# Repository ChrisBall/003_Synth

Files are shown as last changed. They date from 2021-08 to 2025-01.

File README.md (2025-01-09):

# 003_Synth
Code &amp; files for making my audio-lib based synth; 003

Based on a teensy 4.0 with assoc. audio board.

The synth is actually 2 devices - a teensy 4.0 with audio board and a separate "nano every"-based midi controller, with 48 pots, a rotary encoder and OLED display. 

Description of the contents of the code folder:

-"003_synth_main" contains the main arduino sketch.

-"Processing_003_controller_board" contains a basic processing sketch for controlling the synth using [the midibus](https://github.com/sparks/themidibus) library.

-"ctrlr interface" contains a similar midi interface for the [ctrlr software](https://github.com/RomanKubiak/ctrlr).

-"modified audio lib files" contains a modified delay effect for tape simulation. You'll need to replace the originals in the teensy audio lib folder.

-"nano_controller" contains the code that runs on the HMI controller.

You can use this code without building a controller - the synth can be controlled via MIDI. There is a processing program or ctrlr interface in the code folder to facilitate this.

Compilation notes:

-To compile my digital "tape" delay module you'll need to replace the teensy audio lib files (effect_delay.cpp and effect_delay.h) with my versions in the "modified audio lib files" folder.
-Build with "smallest code" option

To get it making a sound, there's some extra work:

-You'll need to set the master volume (CC44, channel 3 - the device only responds to controller values on channel 3). 
-To get sound through the effects chain, set the two distortion gains (CC25, CC41 - channel 3) which default to 0.
-To save a preset (SD card required) send program change on channel 16. To load: program change on channel 3. Presets are saved as plain text in folder "/PRESETS/" on the SD.

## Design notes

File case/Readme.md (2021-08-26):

These are the files for the laser cut case - but I encourage you to design your own controller.

The case is cut from 2mm ply, uses neutrik jack sockets for audio connections, and motherboard standoffs to mount the teensy and a MIDI breakout board.

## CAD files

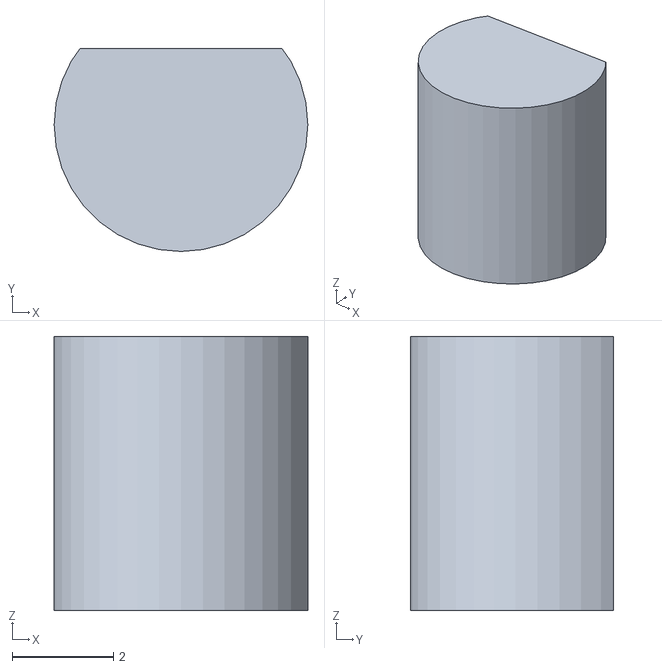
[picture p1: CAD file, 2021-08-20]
case/knobFiller.stl
5.00 x 4.00 x 5.40

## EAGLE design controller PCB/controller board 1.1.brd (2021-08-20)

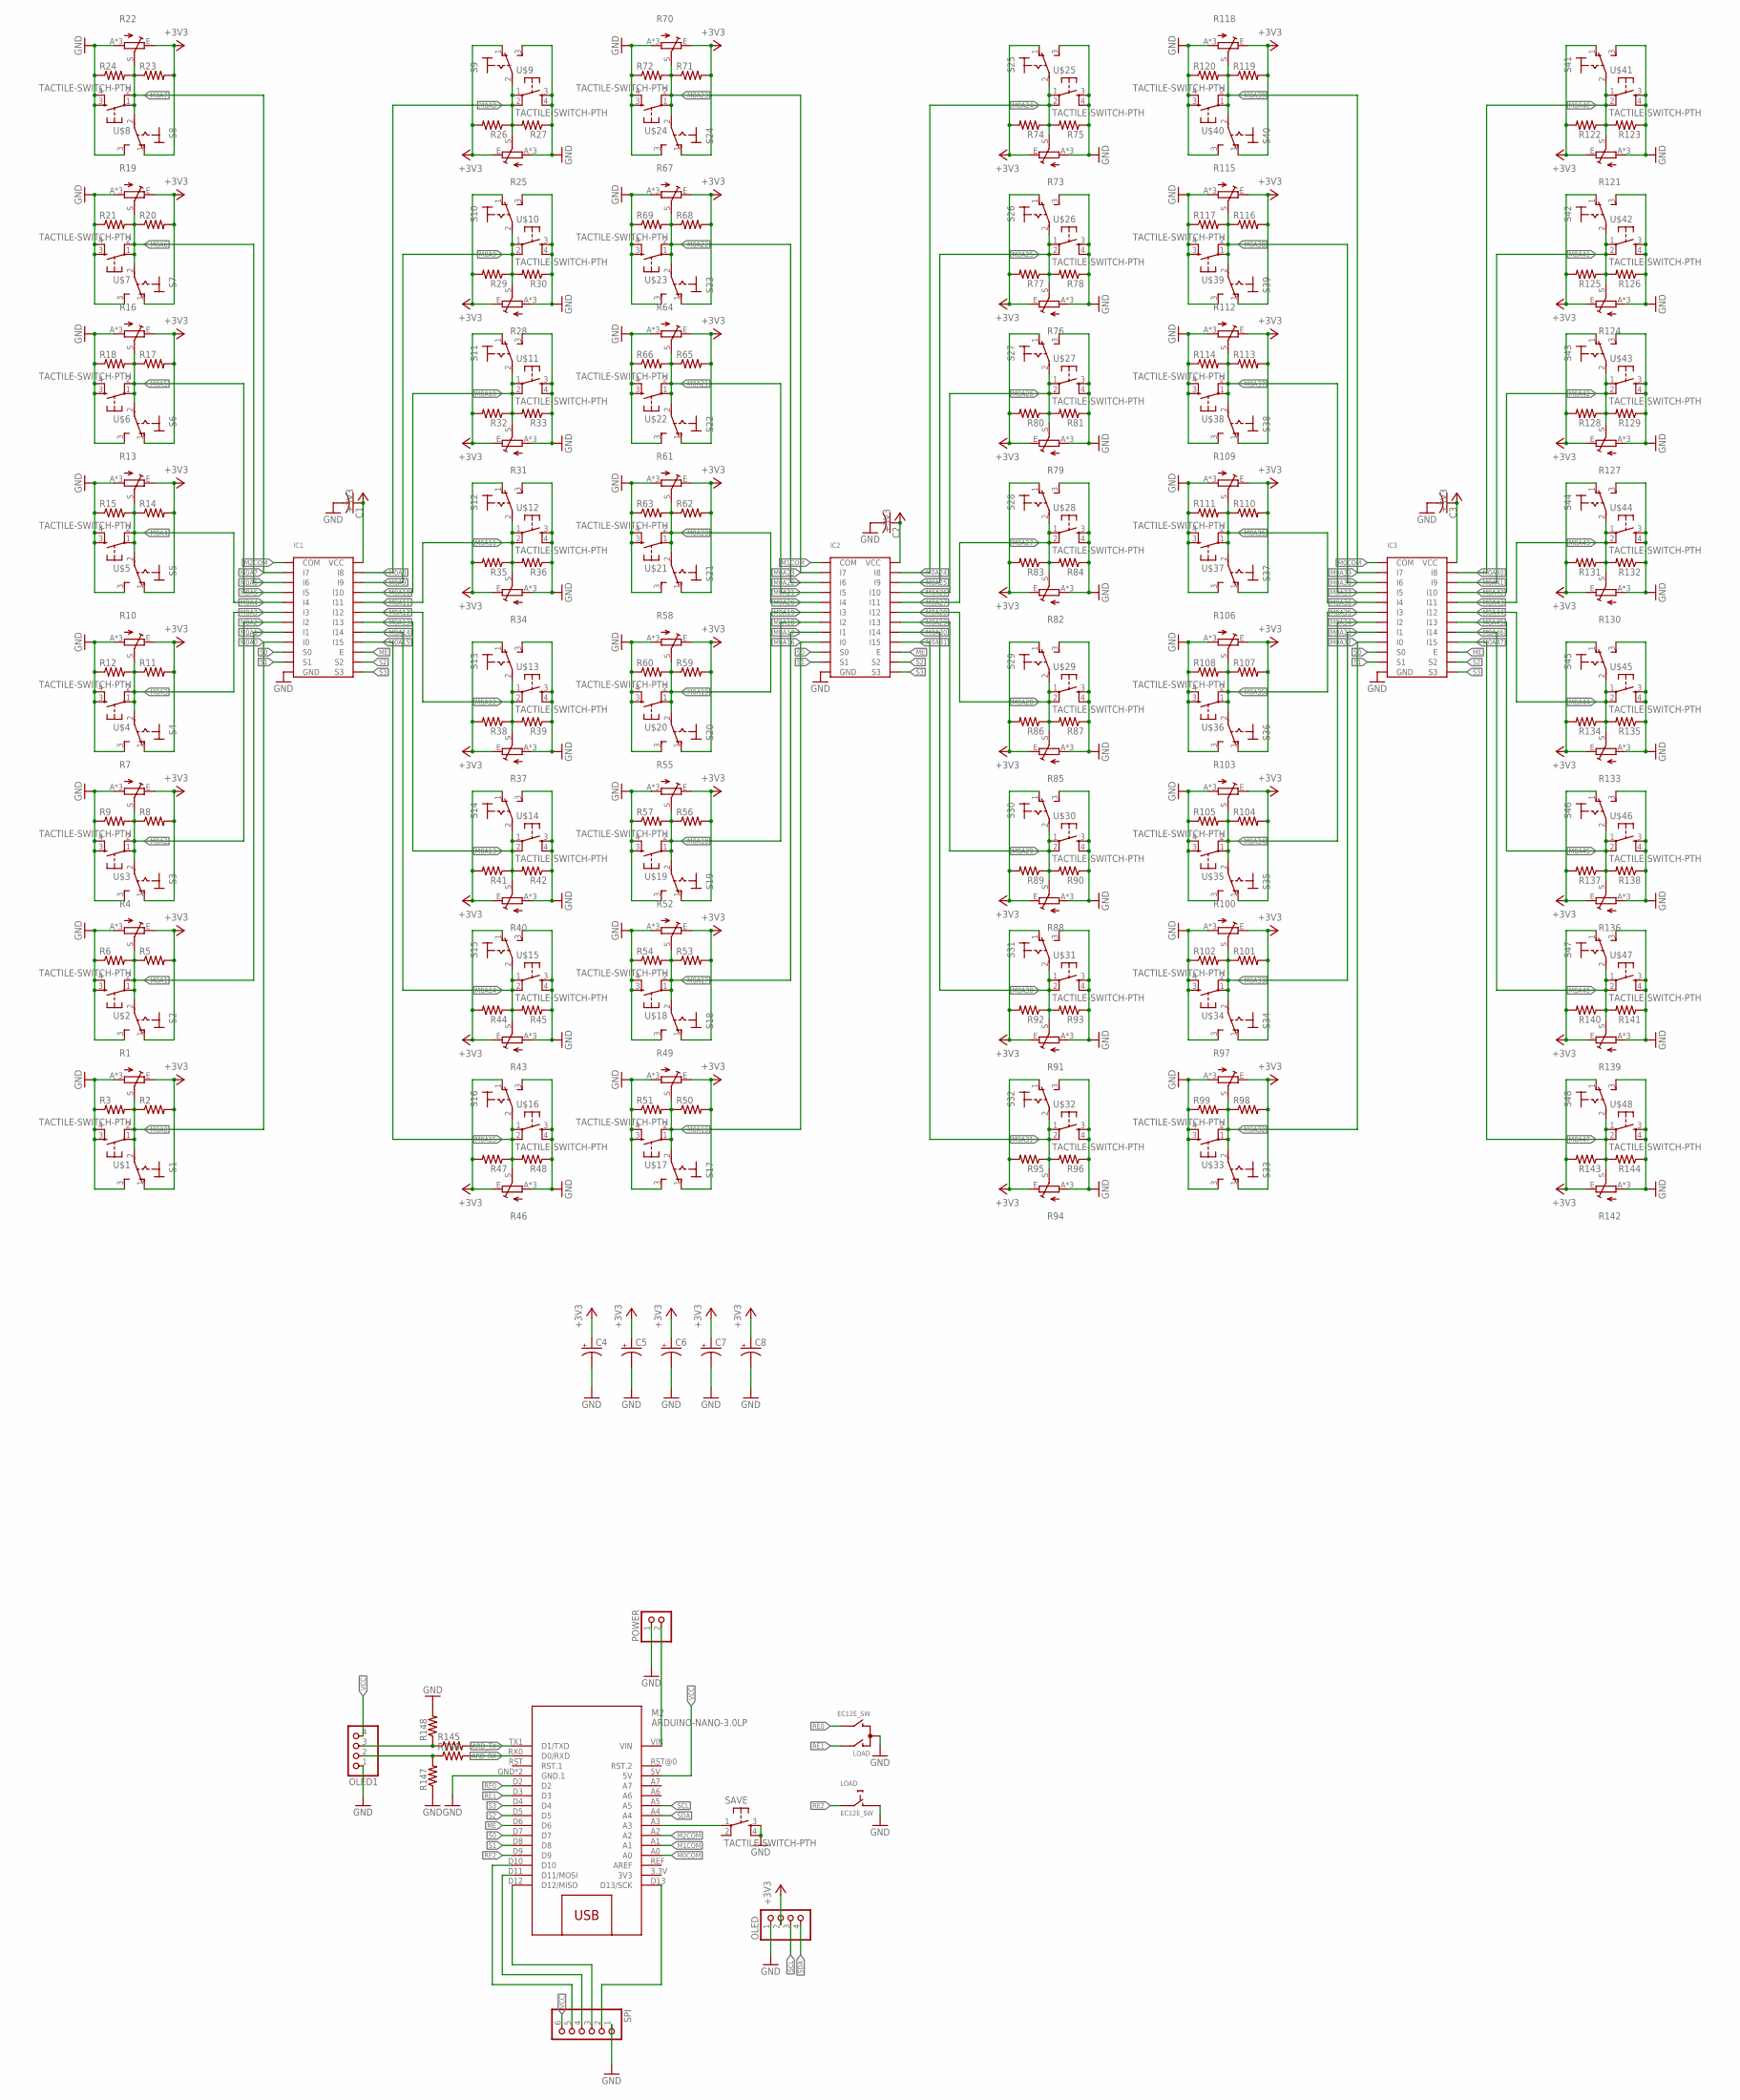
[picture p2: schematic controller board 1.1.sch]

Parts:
C1, C2, C3: C-USC0805; C0805
C4, C5, C6, C7, C8: CPOL-USE2.5-6; E2,5-6
IC1, IC2, IC3: CD74HC4067SM96; LP24SSOP
LOAD: EC12E_SW; ALPS_EC12E_SW
M2: ARDUINO-NANO-3.0LP; ARDUINO-NANO-3.0_LONGPADS
OLED, OLED1: PINHD-1X4; 1X04
POWER: PINHD-1X2; 1X02
R1, R4, R7, R10, R13, R16, R19, R22, R25, R28, R31, R34, R37, R40, R43, R46, R49, R52, R55, R58, R61, R64, R67, R70, R73, R76, R79, R82, R85, R88, R91, R94, R97, R100, R103, R106, R109, R112, R115, R118, R121, R124, R127, R130, R133, R136, R139, R142: TDS3_TRIM_EU-RK09LS; TDS3_RK09L
R2, R3, R5, R6, R8, R9, R11, R12, R14, R15, R17, R18, R20, R21, R23, R24, R26, R27, R29, R30, R32, R33, R35, R36, R38, R39, R41, R42, R44, R45, R47, R48, R50, R51, R53, R54, R56, R57, R59, R60, R62, R63, R65, R66, R68, R69, R71, R72, R74, R75, R77, R78, R80, R81, R83, R84, R86, R87, R89, R90, R92, R93, R95, R96, R98, R99, R101, R102, R104, R105, R107, R108, R110, R111, R113, R114, R116, R117, R119, R120, R122, R123, R125, R126, R128, R129, R131, R132, R134, R135, R137, R138, R140, R141, R143, R144, R145, R146, R147, R148: R-US_M0805; M0805
S1, S2, S3, S4, S5, S6, S7, S8, S9, S10, S11, S12, S13, S14, S15, S16, S17, S18, S19, S20, S21, S22, S23, S24, S25, S26, S27, S28, S29, S30, S31, S32, S33, S34, S35, S36, S37, S38, S39, S40, S41, S42, S43, S44, S45, S46, S47, S48: M9040P
SAVE: TACTILE-SWITCH-PTH; TAC-SWITCH-PTH
SPI: PINHD-1X6; 1X06
U$1, U$2, U$3, U$4, U$5, U$6, U$7, U$8, U$9, U$10, U$11, U$12, U$13, U$14, U$15, U$16, U$17, U$18, U$19, U$20, U$21, U$22, U$23, U$24, U$25, U$26, U$27, U$28, U$29, U$30, U$31, U$32, U$33, U$34, U$35, U$36, U$37, U$38, U$39, U$40, U$41, U$42, U$43, U$44, U$45, U$46, U$47, U$48: TACTILE-SWITCH-PTH; TAC-SWITCH-PTH

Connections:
3V3: M2.3.3V (3V3)
ARD_RX: M2.RX0 (D0/RXD), R146.2
ARD_TX: M2.TX1 (D1/TXD), R145.2
GND: C1.2, C2.2, C3.2, C4.-, C5.-, C6.-, C7.-, C8.-, IC1.GND, IC2.GND, IC3.GND, LOAD.C, LOAD.D (1), M2.GND (GND.1), M2.GND@1 (GND.1), OLED.1, OLED1.1, POWER.1, R1.A, R1.SNAPL (A), R1.SNAPR (A), R3.1, R4.A, R4.SNAPL (A), R4.SNAPR (A), R6.1, R7.A, R7.SNAPL (A), R7.SNAPR (A), R9.1, R10.A, R10.SNAPL (A), R10.SNAPR (A), R12.1, R13.A, R13.SNAPL (A), R13.SNAPR (A), R15.1, R16.A, R16.SNAPL (A), R16.SNAPR (A), R18.1, R19.A, R19.SNAPL (A), R19.SNAPR (A), R21.1, R22.A, R22.SNAPL (A), R22.SNAPR (A), R24.1, R25.A, R25.SNAPL (A), R25.SNAPR (A), R27.1, R28.A, R28.SNAPL (A), R28.SNAPR (A), R30.1, R31.A, R31.SNAPL (A), R31.SNAPR (A), R33.1, R34.A, R34.SNAPL (A), R34.SNAPR (A), R36.1, R37.A, R37.SNAPL (A), R37.SNAPR (A), R39.1, R40.A, R40.SNAPL (A), R40.SNAPR (A), R42.1, R43.A, R43.SNAPL (A), R43.SNAPR (A), R45.1, R46.A, R46.SNAPL (A), R46.SNAPR (A), R48.1, R49.A, R49.SNAPL (A), R49.SNAPR (A), R51.1, R52.A, R52.SNAPL (A), R52.SNAPR (A), R54.1, R55.A, R55.SNAPL (A), R55.SNAPR (A), R57.1, R58.A, R58.SNAPL (A), R58.SNAPR (A), R60.1, R61.A, R61.SNAPL (A), R61.SNAPR (A), R63.1, R64.A, R64.SNAPL (A), R64.SNAPR (A), R66.1, R67.A, R67.SNAPL (A), R67.SNAPR (A), R69.1, R70.A, R70.SNAPL (A), R70.SNAPR (A), R72.1, R73.A, R73.SNAPL (A), R73.SNAPR (A), R75.1, R76.A, R76.SNAPL (A), R76.SNAPR (A), R78.1, R79.A, R79.SNAPL (A), R79.SNAPR (A), R81.1, R82.A, R82.SNAPL (A), R82.SNAPR (A), R84.1, R85.A, R85.SNAPL (A), R85.SNAPR (A), R87.1, R88.A, R88.SNAPL (A), R88.SNAPR (A), R90.1, R91.A, R91.SNAPL (A), R91.SNAPR (A), R93.1, R94.A, R94.SNAPL (A), R94.SNAPR (A), R96.1, R97.A, R97.SNAPL (A), R97.SNAPR (A), R99.1, R100.A, R100.SNAPL (A), R100.SNAPR (A), R102.1, R103.A, R103.SNAPL (A), R103.SNAPR (A), R105.1, R106.A, R106.SNAPL (A), R106.SNAPR (A), R108.1, R109.A, R109.SNAPL (A), R109.SNAPR (A), R111.1, R112.A, R112.SNAPL (A), R112.SNAPR (A), R114.1, R115.A, R115.SNAPL (A), R115.SNAPR (A), R117.1, R118.A, R118.SNAPL (A), R118.SNAPR (A), R120.1, R121.A, R121.SNAPL (A), R121.SNAPR (A), R123.1, R124.A, R124.SNAPL (A), R124.SNAPR (A), R126.1, R127.A, R127.SNAPL (A), R127.SNAPR (A), R129.1, R130.A, R130.SNAPL (A), R130.SNAPR (A), R132.1, R133.A, R133.SNAPL (A), R133.SNAPR (A), R135.1, R136.A, R136.SNAPL (A), R136.SNAPR (A), R138.1, R139.A, R139.SNAPL (A), R139.SNAPR (A), R141.1, R142.A, R142.SNAPL (A), R142.SNAPR (A), R144.1, R147.1, R148.2, S1.3 (S), S2.3 (S), S3.3 (S), S4.3 (S), S5.3 (S), S6.3 (S), S7.3 (S), S8.3 (S), S9.3 (S), S10.3 (S), S11.3 (S), S12.3 (S), S13.3 (S), S14.3 (S), S15.3 (S), S16.3 (S), S17.3 (S), S18.3 (S), S19.3 (S), S20.3 (S), S21.3 (S), S22.3 (S), S23.3 (S), S24.3 (S), S25.3 (S), S26.3 (S), S27.3 (S), S28.3 (S), S29.3 (S), S30.3 (S), S31.3 (S), S32.3 (S), S33.3 (S), S34.3 (S), S35.3 (S), S36.3 (S), S37.3 (S), S38.3 (S), S39.3 (S), S40.3 (S), S41.3 (S), S42.3 (S), S43.3 (S), S44.3 (S), S45.3 (S), S46.3 (S), S47.3 (S), S48.3 (S), SAVE.3, SAVE.4, SPI.1, U$1.3, U$1.4, U$2.3, U$2.4, U$3.3, U$3.4, U$4.3, U$4.4, U$5.3, U$5.4, U$6.3, U$6.4, U$7.3, U$7.4, U$8.3, U$8.4, U$9.3, U$9.4, U$10.3, U$10.4, U$11.3, U$11.4, U$12.3, U$12.4, U$13.3, U$13.4, U$14.3, U$14.4, U$15.3, U$15.4, U$16.3, U$16.4, U$17.3, U$17.4, U$18.3, U$18.4, U$19.3, U$19.4, U$20.3, U$20.4, U$21.3, U$21.4, U$22.3, U$22.4, U$23.3, U$23.4, U$24.3, U$24.4, U$25.3, U$25.4, U$26.3, U$26.4, U$27.3, U$27.4, U$28.3, U$28.4, U$29.3, U$29.4, U$30.3, U$30.4, U$31.3, U$31.4, U$32.3, U$32.4, U$33.3, U$33.4, U$34.3, U$34.4, U$35.3, U$35.4, U$36.3, U$36.4, U$37.3, U$37.4, U$38.3, U$38.4, U$39.3, U$39.4, U$40.3, U$40.4, U$41.3, U$41.4, U$42.3, U$42.4, U$43.3, U$43.4, U$44.3, U$44.4, U$45.3, U$45.4, U$46.3, U$46.4, U$47.3, U$47.4, U$48.3, U$48.4
M0A0: IC1.I0, R1.S, R2.1, R3.2, S1.2, U$1.1, U$1.2
M0A1: IC1.I1, R4.S, R5.1, R6.2, S2.2, U$2.1, U$2.2
M0A2: IC1.I2, R7.S, R8.1, R9.2, S3.2, U$3.1, U$3.2
M0A3: IC1.I3, R10.S, R11.1, R12.2, S4.2, U$4.1, U$4.2
M0A4: IC1.I4, R13.S, R14.1, R15.2, S5.2, U$5.1, U$5.2
M0A5: IC1.I5, R16.S, R17.1, R18.2, S6.2, U$6.1, U$6.2
M0A6: IC1.I6, R19.S, R20.1, R21.2, S7.2, U$7.1, U$7.2
M0A7: IC1.I7, R22.S, R23.1, R24.2, S8.2, U$8.1, U$8.2
M0A8: IC1.I8, R25.S, R26.1, R27.2, S9.2, U$9.1, U$9.2
M0A9: IC1.I9, R28.S, R29.1, R30.2, S10.2, U$10.1, U$10.2
M0A10: IC1.I10, R31.S, R32.1, R33.2, S11.2, U$11.1, U$11.2
M0A11: IC1.I11, R34.S, R35.1, R36.2, S12.2, U$12.1, U$12.2
M0A12: IC1.I12, R37.S, R38.1, R39.2, S13.2, U$13.1, U$13.2
M0A13: IC1.I13, R40.S, R41.1, R42.2, S14.2, U$14.1, U$14.2
M0A14: IC1.I14, R43.S, R44.1, R45.2, S15.2, U$15.1, U$15.2
M0A15: IC1.I15, R46.S, R47.1, R48.2, S16.2, U$16.1, U$16.2
M0A16: IC2.I0, R49.S, R50.1, R51.2, S17.2, U$17.1, U$17.2
M0A17: IC2.I1, R52.S, R53.1, R54.2, S18.2, U$18.1, U$18.2
M0A18: IC2.I2, R55.S, R56.1, R57.2, S19.2, U$19.1, U$19.2
M0A19: IC2.I3, R58.S, R59.1, R60.2, S20.2, U$20.1, U$20.2
M0A20: IC2.I4, R61.S, R62.1, R63.2, S21.2, U$21.1, U$21.2
M0A21: IC2.I5, R64.S, R65.1, R66.2, S22.2, U$22.1, U$22.2
M0A22: IC2.I6, R67.S, R68.1, R69.2, S23.2, U$23.1, U$23.2
M0A23: IC2.I7, R70.S, R71.1, R72.2, S24.2, U$24.1, U$24.2
M0A24: IC2.I8, R73.S, R74.1, R75.2, S25.2, U$25.1, U$25.2
M0A25: IC2.I9, R76.S, R77.1, R78.2, S26.2, U$26.1, U$26.2
M0A26: IC2.I10, R79.S, R80.1, R81.2, S27.2, U$27.1, U$27.2
M0A27: IC2.I11, R82.S, R83.1, R84.2, S28.2, U$28.1, U$28.2
M0A28: IC2.I12, R85.S, R86.1, R87.2, S29.2, U$29.1, U$29.2
M0A29: IC2.I13, R88.S, R89.1, R90.2, S30.2, U$30.1, U$30.2
M0A30: IC2.I14, R91.S, R92.1, R93.2, S31.2, U$31.1, U$31.2
M0A31: IC2.I15, R94.S, R95.1, R96.2, S32.2, U$32.1, U$32.2
M0A32: IC3.I0, R97.S, R98.1, R99.2, S33.2, U$33.1, U$33.2
M0A33: IC3.I1, R100.S, R101.1, R102.2, S34.2, U$34.1, U$34.2
M0A34: IC3.I2, R103.S, R104.1, R105.2, S35.2, U$35.1, U$35.2
M0A35: IC3.I3, R106.S, R107.1, R108.2, S36.2, U$36.1, U$36.2
M0A36: IC3.I4, R109.S, R110.1, R111.2, S37.2, U$37.1, U$37.2
M0A37: IC3.I5, R112.S, R113.1, R114.2, S38.2, U$38.1, U$38.2
M0A38: IC3.I6, R115.S, R116.1, R117.2, S39.2, U$39.1, U$39.2
M0A39: IC3.I7, R118.S, R119.1, R120.2, S40.2, U$40.1, U$40.2
M0A40: IC3.I8, R121.S, R122.1, R123.2, S41.2, U$41.1, U$41.2
M0A41: IC3.I9, R124.S, R125.1, R126.2, S42.2, U$42.1, U$42.2
M0A42: IC3.I10, R127.S, R128.1, R129.2, S43.2, U$43.1, U$43.2
M0A43: IC3.I11, R130.S, R131.1, R132.2, S44.2, U$44.1, U$44.2
M0A44: IC3.I12, R133.S, R134.1, R135.2, S45.2, U$45.1, U$45.2
M0A45: IC3.I13, R136.S, R137.1, R138.2, S46.2, U$46.1, U$46.2
M0A46: IC3.I14, R139.S, R140.1, R141.2, S47.2, U$47.1, U$47.2
M0A47: IC3.I15, R142.S, R143.1, R144.2, S48.2, U$48.1, U$48.2
M0COM: IC3.COM, M2.A0
M1COM: IC2.COM, M2.A1
M2COM: IC1.COM, M2.A2
ME: IC1.E, IC2.E, IC3.E, M2.D6
unnamed: M2.D10, SPI.5
unnamed: M2.D11 (D11/MOSI), SPI.4
unnamed: M2.D12 (D12/MISO), SPI.3
unnamed: M2.VIN, POWER.2
unnamed: M2.A3, SAVE.1
unnamed: M2.D13 (D13/SCK), SPI.2
unnamed: OLED1.3, R145.1, R148.1
unnamed: OLED1.2, R146.1, R147.2
RE0: LOAD.B, M2.D2
RE1: LOAD.A, M2.D3
RE2: LOAD.E (2), M2.D9
S0: IC1.S0, IC2.S0, IC3.S0, M2.D7
S1: IC1.S1, IC2.S1, IC3.S1, M2.D8
S2: IC1.S2, IC2.S2, IC3.S2, M2.D5
S3: IC1.S3, IC2.S3, IC3.S3, M2.D4
SCL: M2.A5, OLED.3
SDA: M2.A4, OLED.4
VCC: C1.1, C2.1, C3.1, C4.+, C5.+, C6.+, C7.+, C8.+, IC1.VCC, IC2.VCC, IC3.VCC, M2.5V, OLED.2, OLED1.4, R1.E, R2.2, R4.E, R5.2, R7.E, R8.2, R10.E, R11.2, R13.E, R14.2, R16.E, R17.2, R19.E, R20.2, R22.E, R23.2, R25.E, R26.2, R28.E, R29.2, R31.E, R32.2, R34.E, R35.2, R37.E, R38.2, R40.E, R41.2, R43.E, R44.2, R46.E, R47.2, R49.E, R50.2, R52.E, R53.2, R55.E, R56.2, R58.E, R59.2, R61.E, R62.2, R64.E, R65.2, R67.E, R68.2, R70.E, R71.2, R73.E, R74.2, R76.E, R77.2, R79.E, R80.2, R82.E, R83.2, R85.E, R86.2, R88.E, R89.2, R91.E, R92.2, R94.E, R95.2, R97.E, R98.2, R100.E, R101.2, R103.E, R104.2, R106.E, R107.2, R109.E, R110.2, R112.E, R113.2, R115.E, R116.2, R118.E, R119.2, R121.E, R122.2, R124.E, R125.2, R127.E, R128.2, R130.E, R131.2, R133.E, R134.2, R136.E, R137.2, R139.E, R140.2, R142.E, R143.2, S1.1 (O), S2.1 (O), S3.1 (O), S4.1 (O), S5.1 (O), S6.1 (O), S7.1 (O), S8.1 (O), S9.1 (O), S10.1 (O), S11.1 (O), S12.1 (O), S13.1 (O), S14.1 (O), S15.1 (O), S16.1 (O), S17.1 (O), S18.1 (O), S19.1 (O), S20.1 (O), S21.1 (O), S22.1 (O), S23.1 (O), S24.1 (O), S25.1 (O), S26.1 (O), S27.1 (O), S28.1 (O), S29.1 (O), S30.1 (O), S31.1 (O), S32.1 (O), S33.1 (O), S34.1 (O), S35.1 (O), S36.1 (O), S37.1 (O), S38.1 (O), S39.1 (O), S40.1 (O), S41.1 (O), S42.1 (O), S43.1 (O), S44.1 (O), S45.1 (O), S46.1 (O), S47.1 (O), S48.1 (O), SPI.6

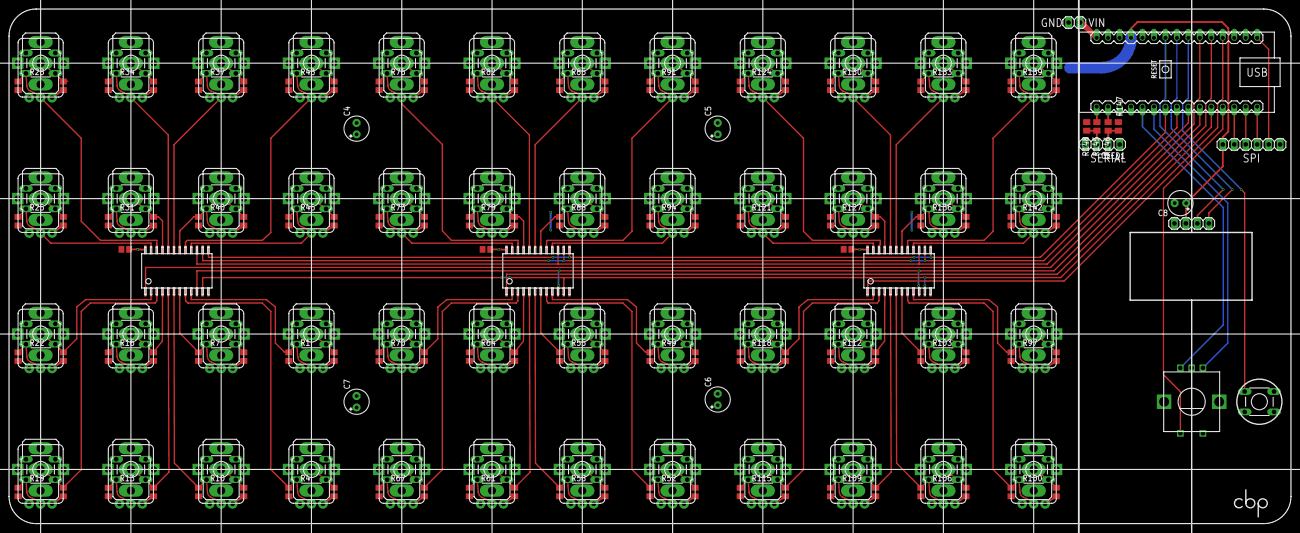
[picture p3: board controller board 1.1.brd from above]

Board: 2 copper layers, 284.0 x 114.0 mm, 262 parts (0 on the bottom side), 73 nets.

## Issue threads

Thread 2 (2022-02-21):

Missing Tape Delay ?

ragededent, 2022-02-21:
Hello,

Thanks for this great work. It is very clear code.

It seems that the TapeDelayEffect library is not included in your project (or maybe it is now included in teensyduino libraries and I couldn't manage to find it). So I changed a little bit to AudioDelayEffect in order to compile.

However I don't get any sound even after changing som control value (44 as you said). Any idea ? I run the 4.1 with SGTL5000.
(EDIT) Sorry, after trying playing a note directly from the code (inside CPU print loop), it does produce sound. It looks like it receives notes and ctrl fomr Live only on channel 3.... ?!

Thanks again for your work.

ChrisBall, 2022-02-22:
Hi!

The modified effect_delay.h and effect delay.cpp files that include the TapeDelayEffect object are here:

https://github.com/ChrisBall/003_Synth/tree/main/code/modified%20audio%20lib%20files

And yes, you're correct - currently it's only set up to receive hardware MIDI over serial3, but I think this is easily altered.

ragededent, 2022-02-22:
Thanks !

Closed 2022-02-22.

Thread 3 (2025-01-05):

tape delay

fitzgreyve, 2025-01-05:
on the off-chance you pick this up:

Same issue as previous poster - Ardiuno IDE not picking up the AudioEffectTapeDelay class when instantiating tapeDelay1

Got your modified effect_delay.h and .cpp files in the same directory as the main INO file.

any thoughts ?

fitzgreyve, 2025-01-06:
Many thanks for your quick reply. I've split the tape delay out in separate local files (i.e removing the standard delay class ) and that now gets picked up OK.

However, I'm getting "Error program exceeds memory space" when clearly it doesn't (on teensy 4.0) so I'm guessing it's probably due to the tape delay queue allocation ?

I'm intending to hack your code about to get a different synth archiecture: I really like your "voice manager" approach and not having to redefine the voice architecture for every available note, one thing I need to figure out is how to apply a global modulation source (e.g. LFO) to all available voices.

ChrisBall, 2025-01-06:
Yep, I guess that's why I opted for building it into the original delay. Years old kludge confirmed. Maybe try uncommenting the memset line?

I definitely have voice parameters I control globally, but it looks like I took the "easy" approach and just made copies of each LFO, ADSR etc. in each voice. I probably did this to allow future development (i.e. 8 voices dedicated to 1 patch, 8 to another, or graceful transitions between patches) then never actually used it.

fitzgreyve, 2025-01-08:
Chris, may thanks for your help - got it working OK.  I copied the modified delayy into the library, then had to built it with "smallest code".
Roughed out a set of controls in Pure Data,  and now tweeking the voice architecture slightly.

fitzgreyve, 2025-01-15:
Sorry to be a nuisance, any thoughts on how to route a global (e.g. ) LFO or performance control into the voice class - just at the limits of my c++ knowledge and can't find any relevant examples.
On the off-chance you might have some thoughts.........

ChrisBall, 2025-01-15:
In my project (because it wasn't essential) I took 2 simpler approaches:

-Copied the LFO so there was one "per voice" - it's a fairly low impact module compared to many others, so this wasn't very costly (compared to the filters which *did* have to be per-voice).

-Polled the object regularly (as with the arpeggiator) as these updates need to happen far less often than audio rate. i.e. if your LFO is truly that, and the audio rates never go high enough to be considered modulation, just implement your own polled LFO with a sine wave.

However, if I was to do it "properly", I might try to set up the voice class to inherit the properties of the AudioStream class that all teensy audio library modules are based on - this would allow you to set up as many audio-rate inputs as you wanted for each voice.

This would mean changing, in voice.h:

`class Voice`

to:

`class Voice : public AudioStream`

and then implement any required AudioStream functions, which IIRC is just update(). There is a good guide from PJRC on writing your own audio lib classes [here](https://www.pjrc.com/teensy/td_libs_AudioNewObjects.html).

fitzgreyve, 2025-01-15:
Many thanks for your help, much appreciated.

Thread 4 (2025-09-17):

missing gerber for teensy synth

carlostau, 2025-09-17:
I can see the controller board is there, but the pcb for the actual teensy synth is not...

carlostau, 2025-09-17:
thanks.. will this work with teensy 4.1? I noticed the pinout for the audioboard is different.

ChrisBall, 2025-09-18:
Should do! [Here's one way to mount it](https://m.media-amazon.com/images/I/61mjG09+U2L._UF350,350_QL80_.jpg).
The main difference you may encounter is that I'm using an SD slot on the audio board to manage presets, and you may wish to use the built in SD slot on the 4.1 instead.

Closed 2025-09-17.

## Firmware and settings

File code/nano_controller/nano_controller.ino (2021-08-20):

/*
   new structure plan
   nano every manages:
   -reading pots
   -display (probably)
   -a set number of presets (255?) but these are actually stored on the teensy 4 SD card as txt files. This opens up the possibility of storing the tape buffer too.

   a "store preset" command simply asks the teensy to store it's pot state (latched or otherwise)
   maybe update pots more when moved??
*/

#include <Encoder.h>
#include <Arduino.h>
#include <U8g2lib.h>
#include <Wire.h>

#define MUX_ENABLE 6
#define MUX_S0 7
#define MUX_S1 8
#define MUX_S2 5
#define MUX_S3 4

#define ENCODER_P0 3
#define ENCODER_P1 2
#define ENCODER_BUTTON 9

#define SAVE_BUTTON A3

#define TOTAL_POTS 48
#define MUX_POTS 16
#define MUX_PINS 3

const char potLabel[][11] = {
  "GLIDE     ", "MODE      ", "OSC1 TYPE ", "OSC2 TYPE ",
  "ARP MODE  ", "ARP RATE  ", "OSC1 DTN  ", "OSC2 DTN  ",
  "VIB AMP   ", "VIB RATE  ", "OSC1 LVL  ", "OSC2 LVL  ",
  "VCF TYPE  ", "VCF Q     ", "VCF FREQ  ", "VCF AMNT  ",

  "ATTACK    ", "DECAY     ", "SUSTAIN   ", "RELEASE   ",
  "EXT FX IN ", "SYN FX IN ", "TREM FREQ ", "TREM AMP  ",
  "DX SHAPE  ", "DX GAIN   ", "BTCRSH BIT", "BTCRSH FS ",
  "GRN SPD   ", "GRN MIX   ", "RING FREQ ", "RING MIX  ",

  "TAPE IN   ", "TAPE LPF  ", "TAPE SPD  ", "TAPE FDBCK",
  "FILT TYPE ", "FILT Q    ", "FILT FREQ ", "FILT MIX  ",
  "DX2 SHAPE ", "DX2 GAIN  ", "RVB AMNT  ", "RVB MIX   ",
  "MASTER    ", "EXT MIX   ", "SYN MIX   ", "FX MIX    "
};

const byte startupLabelLength=22;
const char startupLabel[22][11] {
  "EAT VEG   ",
  "CALL MUM  ",
  "LOVE YOU  ",
  "GOOD FACE ",
  "GOOD EGG  ",
  "YOU WON   ",
  "FUN TIMES ",
  "SYN CITY  ",
  "SIT UP    ",
  "WASH HANDS",
  "TIDY UP   ",
  "STOP IT   ",
  "START IT  ",
  "TEA-TIME  ",
  "EAT WELL  ",
  "DO YOGA   ",
  "AL DENTE  ",
  "ITS ALL OK",
  "CALM DOWN ",
  "CRONKS    ",
  "NICE TIME ",
  "CUDDLE ME "
};

U8G2_SH1106_128X64_NONAME_F_HW_I2C u8g2(U8G2_R0, /* reset=*/ U8X8_PIN_NONE); //2 page buffers (faster than 1, slower than F)
Encoder myEnc(ENCODER_P0, ENCODER_P1);

float reactivity = 0.0025;
float EMA = 1;
float floatValues[TOTAL_POTS];
byte potValues[TOTAL_POTS];

byte muxPins[MUX_PINS] = {A2, A1, A0};
byte potOrder[MUX_POTS] = {9, 8, 7, 6, 11, 10, 5, 4, 12, 13, 2, 3, 14, 15, 0, 1};

byte encPosition = 0;

byte displayFlag = 255;

#define NUM_BUTTONS 2
byte buttonPins[NUM_BUTTONS]  ={9,A3};
byte buttonStates[NUM_BUTTONS]={0,0};

boolean MIDIEnabled = false;
boolean loadEnabled = false;
boolean saveEnabled = false;

void setup() {
  Serial1.begin(31250);
  u8g2.begin();
  displayStartupMessage();
  setupPins();
  initPots();
  MIDIEnabled = true;
}

void loop() {
  displayFlag = 255;

  updateEncoder();
  buttonUpdate();
  updatePots();

  if (displayFlag < 255) {
    displayData(potValues[displayFlag], potLabel[displayFlag]);
  }
}

void setupPins() {
  pinMode(9, INPUT_PULLUP); //encoder switch (load)
  pinMode(A3, INPUT_PULLUP);//tactile switch (save)

  pinMode(MUX_ENABLE, OUTPUT);
  pinMode(MUX_S0, OUTPUT);
  pinMode(MUX_S1, OUTPUT);
  pinMode(MUX_S2, OUTPUT);
  pinMode(MUX_S3, OUTPUT);

  digitalWrite(MUX_ENABLE, 0);
  digitalWrite(MUX_S0, 0);
  digitalWrite(MUX_S1, 0);
  digitalWrite(MUX_S2, 0);
  digitalWrite(MUX_S3, 0);
}

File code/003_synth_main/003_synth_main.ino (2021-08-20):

#include <Audio.h>
#include <Wire.h>
#include <SD.h>
#include <SPI.h>
#include <SerialFlash.h>
#include <MIDI.h>
#include "VoiceManager.h"
#include "FXChain.h"
#include "waveshapeTable.h"

#define NUM_CONTROLS 48

MIDI_CREATE_INSTANCE(HardwareSerial, Serial1, interfaceMIDI); //for MIDI messages coming from interface controller (rx=0, tx=1)
MIDI_CREATE_INSTANCE(HardwareSerial, Serial4, inputMIDI);     //for MIDI messages coming from external MIDI device through 5 pin din (rx=16, tx=17)

AudioInputI2S         ext_input;
AudioOutputI2S        i2s;

AudioControlSGTL5000  sgtl5000_1;

VoiceManager          vm;  //object for polyphonic voices/effects
FXChain               fx;  //object for a monophonic fx chain
AudioMixer4           outputMixer;
AudioSynthWaveformDc  masterLevel;
AudioEffectMultiply   masterMixer;

//chain voices->fx->output mixer
AudioConnection       patchCable0(vm.output, 0, fx.input, 0);
AudioConnection       patchCable1(ext_input, 0, fx.input, 1);
AudioConnection       patchCable2(ext_input, 0, outputMixer, 1);
AudioConnection       patchCable3(vm.output, 0, outputMixer, 2);
AudioConnection       patchCable4(fx.output, 0, outputMixer, 3);
AudioConnection       patchCable5(masterLevel, 0, masterMixer, 0); //using a dc to multiply instead of amp so we can ramp changes over time (no clicking)
AudioConnection       patchCable6(outputMixer, 0, masterMixer, 1);
AudioConnection       patchCable7(masterMixer, 0, i2s, 0);
AudioConnection       patchCable8(masterMixer, 0, i2s, 1);

byte controlValues[NUM_CONTROLS];

void setup() {
  AudioMemory(200);  //200 default (without kpss) //1000 ok //500 ok //200 ok
  Serial.begin(115200);

  sgtl5000_1.enable();
  sgtl5000_1.volume(0.8); //set output headphone volume to a suitable default
  sgtl5000_1.dacVolume(1); //set dac output volume to a suitable default
  sgtl5000_1.lineOutLevel(13); //set line out to high level (range: 13 high to 31 low - values below 13 lead to clipping)
  sgtl5000_1.adcHighPassFilterDisable(); //this reduces some noise on the ext input

  outputMixer.gain(1, 0); //turn down line in mix by default (it's noisy)

  usbMIDI.setHandleNoteOff(onNoteOff);
  usbMIDI.setHandleNoteOn(onNoteOn) ;
  usbMIDI.setHandleControlChange(onControlChange);
  usbMIDI.setHandleProgramChange(onProgramChange);

  interfaceMIDI.setHandleControlChange(onControlChange);
  interfaceMIDI.setHandleProgramChange(onProgramChange);
  interfaceMIDI.begin(MIDI_CHANNEL_OMNI);

  inputMIDI.setHandleNoteOn(onNoteOn);
  inputMIDI.setHandleNoteOff(onNoteOff);
  inputMIDI.setHandleControlChange(onControlChange);
  inputMIDI.begin(MIDI_CHANNEL_OMNI);

  setupSD();
}

int iter = 0;

void loop() {
  usbMIDI.read();
  interfaceMIDI.read();
  inputMIDI.read();
  vm.update(); //purely for arpeggiator

  if (iter++ % 1000000 == 0) {
    Serial.print(AudioProcessorUsage());
    Serial.print('\t');
    Serial.print(AudioProcessorUsageMax());
    Serial.print('\t');
    Serial.print(AudioMemoryUsage());
    Serial.print('\t');
    Serial.println(AudioMemoryUsageMax());
  }
}

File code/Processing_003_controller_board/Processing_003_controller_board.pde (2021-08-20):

import themidibus.*; //Import the midibus library

Pot[][] pots;
int potArrayX=12, potArrayY=4;

Pot preset;

MidiBus myBus; // The MidiBus

void setup() {
  size(1000, 400);

  //init midi bus
  MidiBus.list();
  myBus = new MidiBus(this, 0, "loopMIDI Port");

  //init pots
  pots=new Pot[potArrayX][potArrayY];
  int CCCount=0;
  for (int i=0; i<pots.length; i++) {
    for (int j=0; j<pots[0].length; j++) {
      pots[i][j]=new Pot(33.33+66.66*i, 50+100*j, 50, CCCount);
      CCCount++;
    }
  }
  
  pots[0][0].name="GLIDE";
  pots[0][1].name="POLY/\nMONO/\nMONO CONT.";
  pots[0][2].name="OSC1 TYP";
  pots[0][3].name="OSC2 TYP";

  pots[1][0].name="ARP MODE";
  pots[1][1].name="ARP RATE";
  pots[1][2].name="OSC1 DET";
  pots[1][2].value=0.5;
  pots[1][3].name="OSC2 DET";
  pots[1][3].value=0.5;

  pots[2][0].name="VIB AMP";
  pots[2][1].name="VIB RATE";
  pots[2][2].name="OSC1 GAIN";
  pots[2][3].name="OSC2 GAIN";

  pots[3][0].name="VCF TYP";
  pots[3][1].name="VCF Q";
  pots[3][2].name="VCF MAX";
  pots[3][3].name="VCF AMNT";

  pots[4][0].name="A";
  pots[4][1].name="D";
  pots[4][2].name="S";
  pots[4][3].name="R";

  pots[5][0].name="EXT IN";
  pots[5][1].name="SYN IN";
  pots[5][2].name="TREM FRQ";
  pots[5][3].name="TREM AMP";

  pots[6][0].name="DX SHAPE";
  pots[6][1].name="DX GAIN";
  pots[6][2].name="BTCRSH";
  pots[6][3].name="BTCRSH FS";

  pots[7][0].name="GRN SPD";
  pots[7][1].name="GRN MIX";
  pots[7][2].name="RING FRQ";
  pots[7][3].name="RING MIX";

  pots[8][0].name="TAPE IN";
  pots[8][1].name="TAPE LP";
  pots[8][2].name="TAPE SPD";
  pots[8][3].name="TAPE FDBCK";

  pots[9][0].name="FILT TYPE";
  pots[9][1].name="Q";
  pots[9][2].name="CUTOFF";
  pots[9][3].name="MIX";

  pots[10][0].name="DX2 SHAPE";
  pots[10][1].name="DX2 GAIN";
  pots[10][2].name="RVB AMNT";
  pots[10][3].name="RVB MIX";

  pots[11][0].name="MASTER";
  pots[11][1].name="CLEAN EXT.";
  pots[11][2].name="CLEAN SYNTH";
  pots[11][3].name="FX SYNTH/EXT";
  
  //preset=new Pot();
}

void draw() {
  background(220);

  for (int i=0; i<pots.length; i++) {
    for (int j=0; j<pots[0].length; j++) {
      pots[i][j].draw();
    }
  }
}

void mousePressed() {
  for (int i=0; i<pots.length; i++) {
    for (int j=0; j<pots[0].length; j++) {
      pots[i][j].pressed();
    }
  }
}

void mouseDragged() {
  for (int i=0; i<pots.length; i++) {
    for (int j=0; j<pots[0].length; j++) {
      pots[i][j].dragged();
    }
  }
}

void mouseReleased() {
  for (int i=0; i<pots.length; i++) {
    for (int j=0; j<pots[0].length; j++) {
      pots[i][j].released();
    }
  }
}

void keyPressed() {
  if (key=='0') {
    println("sending all");
    for (int i=0; i<pots.length; i++) {
      for (int j=0; j<pots[0].length; j++) {
        pots[i][j].sendValue();
      }
    }
  }else if(key=='l'){
    myBus.sendMessage(0xC1,14);
  }
}

void noteOn(int channel, int pitch, int velocity) {
  myBus.sendNoteOn(channel, pitch, velocity);
  println();
  println("Note On:");
  println("--------");
  println("Channel:"+channel);
  println("Pitch:"+pitch);
  println("Velocity:"+velocity);
}

void noteOff(int channel, int pitch, int velocity) {
  myBus.sendNoteOff(channel-1, pitch, velocity);
  // Receive a noteOff
  println();
  println("Note Off:");
  println("--------");
  println("Channel:"+channel);
  println("Pitch:"+pitch);
  println("Velocity:"+velocity);
}

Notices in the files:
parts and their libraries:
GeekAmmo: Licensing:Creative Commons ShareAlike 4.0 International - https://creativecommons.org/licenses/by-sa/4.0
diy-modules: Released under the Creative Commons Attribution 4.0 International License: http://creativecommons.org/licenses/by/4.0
